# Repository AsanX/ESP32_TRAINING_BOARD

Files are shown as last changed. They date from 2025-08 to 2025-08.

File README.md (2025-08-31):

# ESP32_TRAINING_BOARD

ESP32 Training board is designed to have multiple things to play with so there are lot's of opportunities to learn the ESP32.
I made this board so i can remotely open our front door from 4th floor and figured i could do something else with it too.

- USB-C Charging, programming and serial monitor
- 18650 Battery with commonly used TP4056 charging circuit
- RGB Led
- Button / Encoder
- TMP100 12Bit I2C Temperature sensor
- OLED I2C Display
- Few optocoupler for inputs and outputs

# Alredy found mistakes from HW 1.0
## Enable pin and auto reset
When using automatic reset for programming, there needs to be a uF range capacitor on enable.
This is to make sure the IO0 pin is given some time to pull low to enter the download mode before the en pin gets HIGH.
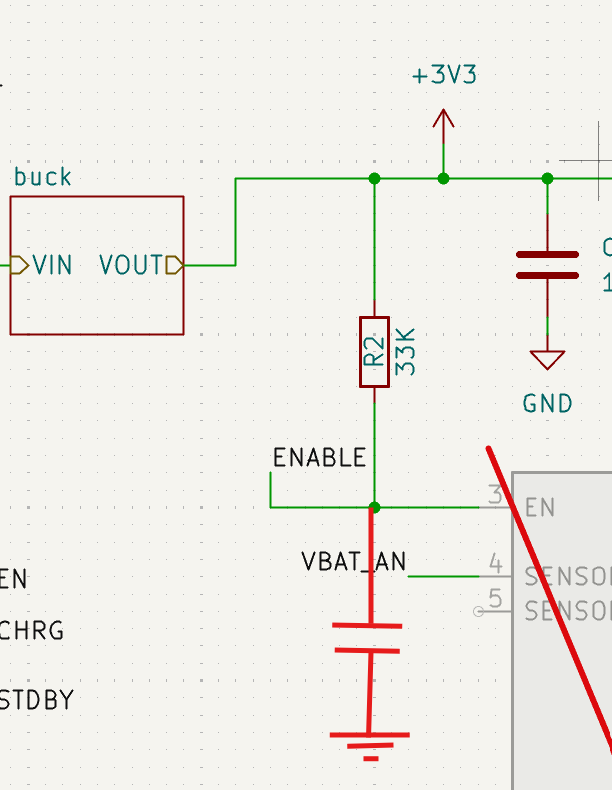
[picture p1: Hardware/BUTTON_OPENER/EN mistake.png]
Alt text for image


## TP4056 temperature pin
Datasheet clearly says that the pin should be pulled low if there are no temperature sensor on the battery
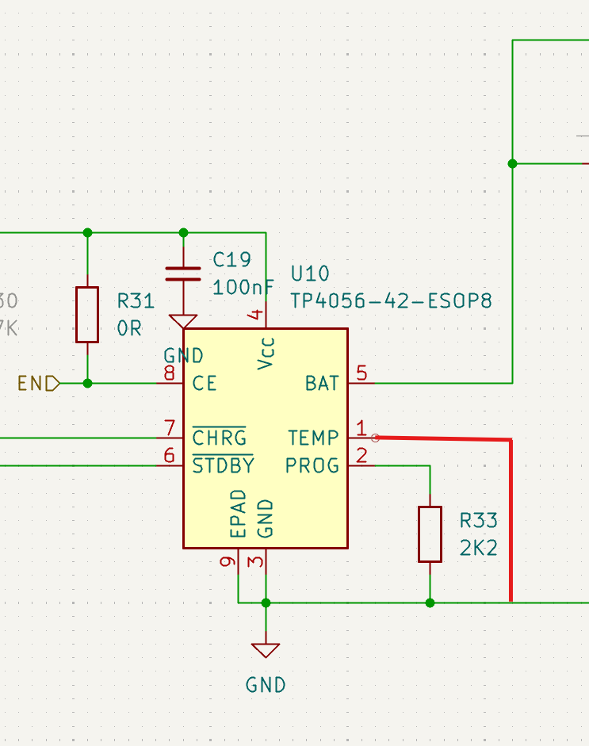
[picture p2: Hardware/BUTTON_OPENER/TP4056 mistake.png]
Alt_text_for_image


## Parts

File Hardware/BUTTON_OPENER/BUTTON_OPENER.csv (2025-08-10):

Comment | Reference | Footprint | JLCPCB Part #
100nF | C4,C5,C6,C7,C8,C10,C11,C12,C13,C14,C15,C17,C18,C19 | Capacitor_SMD:C_0603_1608Metric | C14663
1K | R6,R7,R8,R13,R15,R16,R18,R21,R25,R32 | Resistor_SMD:R_0603_1608Metric | C21190
TCMT1100 | U4,U5,U6,U7 | Package_SO:SOP-4_4.4x2.6mm_P1.27mm | C123196
33K | R2,R3,R9,R17 | Resistor_SMD:R_0603_1608Metric | C4216
47K | R14,R19,R24 | Resistor_SMD:R_0603_1608Metric | C25819
10K | R1,R22,R26 | Resistor_SMD:R_0603_1608Metric | C25804
10uF | C1,C3,C20 | Capacitor_SMD:C_0603_1608Metric | C19702
5K1 | R34,R35 | Resistor_SMD:R_0603_1608Metric | C23186
12K | R23,R27 | Resistor_SMD:R_0603_1608Metric | C22790
3K3 | R11,R12 | Resistor_SMD:R_0603_1608Metric | C22978
6K8 | R4,R5 | Resistor_SMD:R_0603_1608Metric | C23212
BC847 | Q1,Q2 | Package_TO_SOT_SMD:SOT-23 | C475630
4.7uF | C9,C16 | Capacitor_SMD:C_0603_1608Metric | C19666
SUNTEK SK6615CS5 | U11 | Package_TO_SOT_SMD:SOT-23-5 | C2986199
TP4056-42-ESOP8 | U10 | Package_SO:SOIC-8-1EP_3.9x4.9mm_P1.27mm_EP2.41x3.3mm_ThermalVias | C16581
DW01A | U9 | Package_TO_SOT_SMD:SOT-23-6 | C2927799
CP2102N | U8 | Package_DFN_QFN:QFN-24-1EP_4x4mm_P0.5mm_EP2.6x2.6mm | C969151
TMP100 | U3 | Package_TO_SOT_SMD:SOT-23-6 | C31810
120K | R37 | Resistor_SMD:R_0603_1608Metric | C25808
2K2 | R33 | Resistor_SMD:R_0603_1608Metric | C4190
0R | R31 | Resistor_SMD:R_0603_1608Metric | C21189
100R | R28 | Resistor_SMD:R_0603_1608Metric | C22775
8K2 | R20 | Resistor_SMD:R_0603_1608Metric | C25981
1K5 | R10 | Resistor_SMD:R_0603_1608Metric | C22843
BSD840N | Q3 | Package_TO_SOT_SMD:SOT-363_SC-70-6 | C466988
2.2uH | L1 | Inductor_SMD:L_APV_ANR4026 | C167854
USB_C_Receptacle_USB2.0_14P | J7 | Connector_USB:USB_C_Receptacle_G-Switch_GT-USB-7010ASV | C2927039
1uF | C2 | Capacitor_SMD:C_0603_1608Metric | C106248

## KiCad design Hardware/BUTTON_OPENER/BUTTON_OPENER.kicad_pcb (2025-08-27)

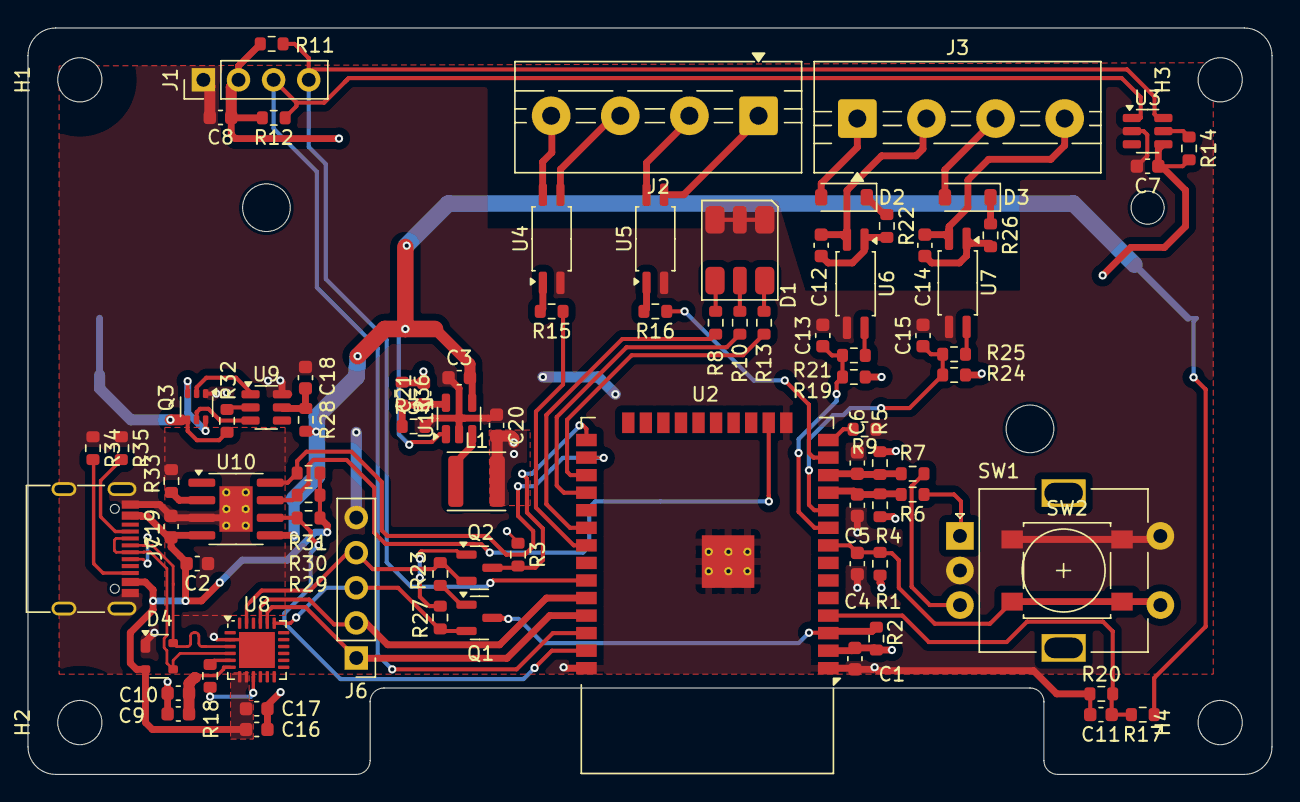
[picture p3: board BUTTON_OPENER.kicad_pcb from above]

Board: 2 copper layers, 90.0 x 54.0 mm, 88 parts (1 on the bottom side), 67 nets.

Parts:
BT1: 18650 holder; BatteryHolder_Keystone_1042_1x18650
C1, C3, C20: 10uF 6.3V X7R; C_0603_1608Metric
C2: 1uF 10V X7R; C_0603_1608Metric
C4, C5, C6, C7, C8, C10, C11, C12, C13, C14, C15, C17, C18, C19: 100nF 10V X7R; C_0603_1608Metric
C9, C16: 4.7uF 10V X7R; C_0603_1608Metric
C21: 22pF; C_0603_1608Metric
D1: Inolux_IN-P55TATRGB; LED_Inolux_IN-P55TATRGB_PLCC6_5.0x5.5mm_P1.8mm
D2, D3: D; D_SOD-123
D4: SP0503BAHT; SOT-143
H1, H2, H3, H4: MountingHole; MountingHole_3.2mm_M3
J1: N/A; PinHeader_1x04_P2.54mm_Vertical
J2, J3: Screw_Terminal_01x04; TerminalBlock_MaiXu_MX126-5.0-04P_1x04_P5.00mm
J6: Conn_01x05; PinHeader_1x05_P2.54mm_Vertical
J7: USB_C_Receptacle_USB2.0_14P; USB_C_Receptacle_G-Switch_GT-USB-7010ASV
L1: 2.2uH; L_APV_ANR4020
Q1, Q2: BC847; SOT-23
Q3: BSD840N; SOT-363_SC-70-6
R1, R22, R26: 10K; R_0603_1608Metric
R2, R3, R9, R17: 33K; R_0603_1608Metric
R4, R5: 6K8; R_0603_1608Metric
R6, R7, R8, R13, R15, R16, R18, R21, R25, R32: 1K; R_0603_1608Metric
R10: 1K5; R_0603_1608Metric
R11, R12: 3K3; R_0603_1608Metric
R14, R19, R24, R29, R30: 47K; R_0603_1608Metric
R20: 8K2; R_0603_1608Metric
R23, R27: 12K; R_0603_1608Metric
R28: 100R; R_0603_1608Metric
R31: 0R; R_0603_1608Metric
R33: 2K2; R_0603_1608Metric
R34, R35: 5K1; R_0603_1608Metric
R36: 540K; R_0603_1608Metric
R37: 120K; R_0603_1608Metric
SW1: N/A; RotaryEncoder_Alps_EC11E-Switch_Vertical_H20mm
SW2: SW_Push; SW_SPST_B3S-1000
U2: ESP32-WROOM; ESP32-WROOM-32D
U3: TMP100; SOT-23-6
U4, U5, U6, U7: TCMT1100; SOP-4_4.4x2.6mm_P1.27mm
U8: CP2102N; QFN-24-1EP_4x4mm_P0.5mm_EP2.6x2.6mm
U9: DW01A; SOT-23-6
U10: TP4056-42-ESOP8; SOIC-8-1EP_3.9x4.9mm_P1.27mm_EP2.41x3.3mm_ThermalVias
U11: SUNTEK SK6615CS5; SOT-23-5

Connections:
+3V3: C1.2, C7.1, C8.1, C20.2, C21.2, J1.2, L1.2, R1.1, R2.1, R3.1, R4.1, R5.1, R11.2, R12.2, R14.2, R19.2, R24.2, R36.1, U2.2 (VDD), U3.4 (V+)
/B: R13.1, U2.27 (IO16)
/CHRG: R30.1, U2.16 (IO13), U10.7 (~CHRG)
/D+: D4.4 (K), J7.A6 (D+), J7.B6 (D+), U8.3 (D+)
/D-: D4.3 (K), J7.A7 (D-), J7.B7 (D-), U8.4 (D-)
/DTR: J6.4, Q2.2 (E), R23.1, U8.23 (~DTR)
/EN: R31.1, U2.26 (IO4), U10.8 (CE)
/ENABLE: Q1.3 (C), R2.2, U2.3 (EN)
/ENC_A: C5.2, R4.2, R6.2, U2.11 (IO26)
/ENC_B: C6.2, R5.2, R7.2, U2.12 (IO27)
/ENC_SW: C4.2, R1.2, SW1.S1, SW2.2, U2.8 (IO32)
/G: R10.1, U2.28 (IO17)
/GPIO0: Q2.3 (C), R3.2, U2.25 (IO0)
/OPTO_1: R15.1, U2.31 (IO19)
/OPTO_2: R16.1, U2.13 (IO14)
/OPTO_IN1: C13.1, R19.1, R21.2, U2.9 (IO33)
/OPTO_IN2: C15.1, R24.1, R25.2, U2.10 (IO25)
/R: R8.1, U2.30 (IO18)
/RTS: J6.3, Q1.2 (E), R27.1, U8.19 (~RTS)
/RXD: J6.2, U2.34 (RXD0/IO3), U8.21 (TXD)
/SCL: J1.3, R12.1, U2.36 (IO22), U3.1 (SCL)
/SDA: J1.4, R11.1, U2.33 (IO21), U3.6 (SDA)
/STDBY: R29.1, U2.37 (IO23), U10.6 (~STDBY)
/TXD: J6.1, U2.35 (TXD0/IO1), U8.20 (RXD)
/VBAT: BT1.1 (+), C3.2, R17.1, R28.2, U10.5 (BAT), U11.1 (EN), U11.4 (VIN)
/VBAT_AN: C11.1, R17.2, R20.1, U2.4 (SENSOR_VP)
/VBUS: C2.2, C16.2, C17.1, C19.1, D4.2 (K), J7.A4 (VBUS), J7.A9 (VBUS), J7.B4 (VBUS), J7.B9 (VBUS), R29.2, R30.2, R31.2, U8.7 (VREGIN), U8.8 (VBUS), U10.4 (V_{CC})
GND: C1.1, C2.1, C3.1, C4.1, C5.1, C6.1, C7.2, C8.2, C9.1, C10.2, C11.2, C13.2, C15.2, C16.1, C17.2, C18.2, C19.2, C20.1, D1.1 (KB), D1.2 (KR), D1.3 (KG), D4.1 (A), J1.1, J6.5, J7.A1 (GND), J7.A12 (GND), J7.B1 (GND), J7.B12 (GND), J7.S1 (SHIELD), Q3.1 (S), R9.2, R20.2, R33.1, R34.1, R35.1, R37.2, SW1.C, SW1.S2, SW2.1, U2.1 (GND), U2.15 (GND), U2.38 (GND), U2.39 (GND), U3.2 (GND), U4.2, U5.2, U6.3, U7.3, U8.2 (GND), U8.25 (GND), U9.6 (GND), U10.3 (GND), U10.9 (EPAD), U11.2 (GND)
unnamed: BT1.2 (-), Q3.4 (S), R32.1
unnamed: C12.1, R22.2, U6.1
unnamed: C14.1, R26.2, U7.1
unnamed: D1.6 (AB), R13.2
unnamed: D1.4 (AG), R8.2
unnamed: D1.5 (AR), R10.2
unnamed: D2.2 (A), J3.1
unnamed: D2.1 (K), R22.1
unnamed: D3.2 (A), J3.3
unnamed: D3.1 (K), R26.1
unnamed: J2.1, U5.3
unnamed: J2.2, U5.4
unnamed: J2.3, U4.3
unnamed: J2.4, U4.4
unnamed: C12.2, J3.2, U6.2
unnamed: C14.2, J3.4, U7.2
unnamed: J7.A5 (CC1), R35.2
unnamed: J7.B5 (CC2), R34.2
unnamed: Q1.1 (B), R23.2
unnamed: Q2.1 (B), R27.2
unnamed: Q3.3 (D), Q3.6 (D)
unnamed: Q3.2 (G), U9.1 (OD)
unnamed: Q3.5 (G), U9.3 (OC)
unnamed: R6.1, SW1.A
unnamed: R7.1, SW1.B
unnamed: R15.2, U4.1
unnamed: R16.2, U5.1
unnamed: R21.1, U6.4
unnamed: R25.1, U7.4
unnamed: R9.1, U2.14 (IO12)
unnamed: R14.1, U3.5 (ADD0)
unnamed: C9.2, C10.1, U8.6 (VDD)
unnamed: R18.1, U8.5 (VIO)
unnamed: R18.2, U8.9 (~RST)
unnamed: R32.2, U9.2 (CS)
unnamed: C18.1, R28.1, U9.5 (VCC)
unnamed: R33.2, U10.2 (PROG)
unnamed: C21.1, R36.2, R37.1, U11.5 (FB)
unnamed: L1.1, U11.3 (SW)

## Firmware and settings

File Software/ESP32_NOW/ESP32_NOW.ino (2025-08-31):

#include <Wire.h>
#include <Adafruit_GFX.h>
#include <Adafruit_SSD1306.h>
#include "ESP32_NOW.h"
#include "WiFi.h"

#define SCREEN_WIDTH 128  // OLED width in pixels
#define SCREEN_HEIGHT 64  // OLED height in pixels

#define ESPNOW_WIFI_CHANNEL 6

uint8_t broadcastAddress[] = {0xFF, 0xFF, 0xFF, 0xFF, 0xFF, 0xFF};

// Declaration for an SSD1306 display connected to I2C (SDA, SCL pins)
#define OLED_RESET    -1  // Reset pin not used
Adafruit_SSD1306 display(SCREEN_WIDTH, SCREEN_HEIGHT, &Wire, OLED_RESET);

// Set up the rgb led names
uint8_t ledR = 18;
uint8_t ledG = 17;
uint8_t ledB = 16;

#define CHARGING_PIN 13     // Pin 13 (Charging signal from TP4056)
#define STANDBY_PIN 23      // Pin 23 (STANDBY signal from TP4056)
#define EN_PIN 4            // Pin 4  (EN signal for TP4056)
#define SW_PIN 32           // Pin 32 (SW / Encoder SW)

struct Input {
  const uint8_t PIN;
  uint32_t events;
  bool active;
};

Input charging = {CHARGING_PIN, 0, false};
Input standby = {STANDBY_PIN, 0, false};
Input sw = {SW_PIN, 0, false};


/* Interrupt service*/
void ARDUINO_ISR_ATTR isr(void *arg) 
{
  Input *s = static_cast<Input *>(arg);
  s->events += 1;
  s->active = true;
}

class ESP_NOW_Broadcast_Peer : public ESP_NOW_Peer {
public:
  // Constructor of the class using the broadcast address
  ESP_NOW_Broadcast_Peer(uint8_t channel, wifi_interface_t iface, const uint8_t *lmk) : ESP_NOW_Peer(ESP_NOW.BROADCAST_ADDR, channel, iface, lmk) {}

  // Destructor of the class
  ~ESP_NOW_Broadcast_Peer() {
    remove();
  }

  // Function to properly initialize the ESP-NOW and register the broadcast peer
  bool begin() {
    if (!ESP_NOW.begin() || !add()) {
      log_e("Failed to initialize ESP-NOW or register the broadcast peer");
      return false;
    }
    return true;
  }

  // Function to send a message to all devices within the network
  bool send_message(const uint8_t *data, size_t len) {
    if (!send(data, len)) {
      log_e("Failed to broadcast message");
      return false;
    }
    return true;
  }
};

/* Global Variables */
uint32_t msg_count = 0;

// Create a broadcast peer object
ESP_NOW_Broadcast_Peer broadcast_peer(ESPNOW_WIFI_CHANNEL, WIFI_IF_STA, nullptr);

// the setup routine runs once when you press reset:
void setup() {
  Serial.begin(115200);
  delay(10);

   // Initialize OLED
  if(!display.begin(SSD1306_SWITCHCAPVCC, 0x3C)) {  // Address 0x3C for 128x64
    Serial.println(F("SSD1306 allocation failed"));
    while(true);  // Don't proceed, loop forever
  }

  display.clearDisplay();
  display.setTextSize(1);             // Normal 1:1 pixel scale
  display.setTextColor(SSD1306_WHITE); // Draw white text
  display.setCursor(0, 0);            // Start at top-left corner
  display.display();                  // Show on screen

  ledcAttach(ledR, 3000, 8);  // 12 kHz PWM, 8-bit resolution
  ledcAttach(ledG, 3000, 8);
  ledcAttach(ledB, 3000, 8);

  // Set pinmodes
  pinMode(CHARGING_PIN, INPUT_PULLUP);   
  pinMode(STANDBY_PIN, INPUT_PULLUP);  
  pinMode(SW_PIN, INPUT_PULLUP);  
  pinMode(EN_PIN, OUTPUT_OPEN_DRAIN); 

  attachInterruptArg(SW_PIN, isr, &sw, FALLING);

  analogReadResolution(12);

  // Initialize the Wi-Fi module
  WiFi.mode(WIFI_STA);
  WiFi.setChannel(ESPNOW_WIFI_CHANNEL);
  while (!WiFi.STA.started()) {
    delay(100);
  }

  Serial.println("ESP-NOW Example - Broadcast Master");
  Serial.println("Wi-Fi parameters:");
  Serial.println("  Mode: STA");
  Serial.println("  MAC Address: " + WiFi.macAddress());
  Serial.printf("  Channel: %d\n", ESPNOW_WIFI_CHANNEL);

  // Register the broadcast peer
  if (!broadcast_peer.begin()) {
    Serial.println("Failed to initialize broadcast peer");
    Serial.println("Reebooting in 5 seconds...");
    delay(5000);
    ESP.restart();
  }

  Serial.printf("ESP-NOW version: %d, max data length: %d\n", ESP_NOW.getVersion(), ESP_NOW.getMaxDataLen());

  Serial.println("Setup complete. Broadcasting messages every 5 seconds.");

}


// void loop runs over and over again
void loop() 
{
  if (sw.active == true)
  {
    ledcWrite(ledB, 255);
    sw.active = false;

      // Broadcast a message to all devices within the network
    char data[32];
    snprintf(data, sizeof(data), "Hello, World! #%lu", msg_count++);

    Serial.printf("Broadcasting message: %s\n", data);

    if (!broadcast_peer.send_message((uint8_t *)data, sizeof(data))) {
      Serial.println("Failed to broadcast message");
    }

  }

  static uint32_t lastMillis = 0;
  if (millis() - lastMillis > 3000) {
    lastMillis = millis();
    ledcWrite(ledB,0);
    ledcWrite(ledR,0);
    ledcWrite(ledG,0);
  }
}

/* Use this to convert ADC millivolts to Battery millivolts */
uint16_t adcmV_to_batmV(uint16_t mV)
{
  // Reverse voltage divider to get actual battery voltage (also in millivolts)
  // Vbat = Vadc * (R1 + R2) / R2
  uint16_t vBat = (uint32_t)mV * (33000 + 8200) / 8200;

  return vBat;
}

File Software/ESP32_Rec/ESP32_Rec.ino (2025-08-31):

/*
    ESP-NOW Broadcast Slave
    Lucas Saavedra Vaz - 2024

    This sketch demonstrates how to receive broadcast messages from a master device using the ESP-NOW protocol.

    The master device will broadcast a message every 5 seconds to all devices within the network.

    The slave devices will receive the broadcasted messages. If they are not from a known master, they will be registered as a new master
    using a callback function.
*/

#include <Wire.h>
#include <Adafruit_GFX.h>
#include <Adafruit_SSD1306.h>

#include "ESP32_NOW.h"
#include "WiFi.h"

#include <esp_mac.h>  // For the MAC2STR and MACSTR macros

#include <vector>

/* Definitions */

#define ESPNOW_WIFI_CHANNEL 6

#define OPTO1 19
#define OPTO2 14
// Set up the rgb led names
const uint8_t ledR = 18;
const uint8_t ledG = 17;
const uint8_t ledB = 16;

/* Classes */

// Creating a new class that inherits from the ESP_NOW_Peer class is required.

class ESP_NOW_Peer_Class : public ESP_NOW_Peer {
public:
  // Constructor of the class
  ESP_NOW_Peer_Class(const uint8_t *mac_addr, uint8_t channel, wifi_interface_t iface, const uint8_t *lmk) : ESP_NOW_Peer(mac_addr, channel, iface, lmk) {}

  // Destructor of the class
  ~ESP_NOW_Peer_Class() {}

  // Function to register the master peer
  bool add_peer() {
    if (!add()) {
      log_e("Failed to register the broadcast peer");
      return false;
    }
    return true;
  }

  // Function to print the received messages from the master
  void onReceive(const uint8_t *data, size_t len, bool broadcast) {
    Serial.printf("Received a message from master " MACSTR " (%s)\n", MAC2STR(addr()), broadcast ? "broadcast" : "unicast");
    Serial.printf("  Message: %s\n", (char *)data);
    ledcWrite(ledG, 200);
    digitalWrite(OPTO1, HIGH);
    digitalWrite(OPTO2, LOW);

  }
};
 
/* Global Variables */

// List of all the masters. It will be populated when a new master is registered
// Note: Using pointers instead of objects to prevent dangling pointers when the vector reallocates
std::vector<ESP_NOW_Peer_Class *> masters;

/* Callbacks */

// Callback called when an unknown peer sends a message
void register_new_master(const esp_now_recv_info_t *info, const uint8_t *data, int len, void *arg) {
  if (memcmp(info->des_addr, ESP_NOW.BROADCAST_ADDR, 6) == 0) {
    Serial.printf("Unknown peer " MACSTR " sent a broadcast message\n", MAC2STR(info->src_addr));
    Serial.println("Registering the peer as a master");

    ESP_NOW_Peer_Class *new_master = new ESP_NOW_Peer_Class(info->src_addr, ESPNOW_WIFI_CHANNEL, WIFI_IF_STA, nullptr);
    if (!new_master->add_peer()) {
      Serial.println("Failed to register the new master");
      delete new_master;
      return;
    }
    masters.push_back(new_master);
    Serial.printf("Successfully registered master " MACSTR " (total masters: %zu)\n", MAC2STR(new_master->addr()), masters.size());
  } else {
    // The slave will only receive broadcast messages
    log_v("Received a unicast message from " MACSTR, MAC2STR(info->src_addr));
    log_v("Igorning the message");
  }
}

/* Main */

void setup() {
  Serial.begin(115200);

  pinMode(OPTO1, OUTPUT);
  pinMode(OPTO2, OUTPUT);

  digitalWrite(OPTO1, LOW);
  digitalWrite(OPTO2, HIGH);

  ledcAttach(ledG, 3000, 8);

  // Initialize the Wi-Fi module
  WiFi.mode(WIFI_STA);
  WiFi.setChannel(ESPNOW_WIFI_CHANNEL);
  while (!WiFi.STA.started()) {
    delay(100);
  }

  Serial.println("ESP-NOW Example - Broadcast Slave");
  Serial.println("Wi-Fi parameters:");
  Serial.println("  Mode: STA");
  Serial.println("  MAC Address: " + WiFi.macAddress());
  Serial.printf("  Channel: %d\n", ESPNOW_WIFI_CHANNEL);

  // Initialize the ESP-NOW protocol
  if (!ESP_NOW.begin()) {
    Serial.println("Failed to initialize ESP-NOW");
    Serial.println("Reeboting in 5 seconds...");
    delay(5000);
    ESP.restart();
  }

  Serial.printf("ESP-NOW version: %d, max data length: %d\n", ESP_NOW.getVersion(), ESP_NOW.getMaxDataLen());

  // Register the new peer callback
  ESP_NOW.onNewPeer(register_new_master, nullptr);

  Serial.println("Setup complete. Waiting for a master to broadcast a message...");
}

void loop() {
  // Print debug information every 10 seconds
  static unsigned long last_debug = 0;
  if (millis() - last_debug > 10000) {
    ledcWrite(ledG, 0);
    digitalWrite(OPTO1, LOW);
    digitalWrite(OPTO2, HIGH);
    last_debug = millis();
    Serial.printf("Registered masters: %zu\n", masters.size());
    for (size_t i = 0; i < masters.size(); i++) {
      if (masters[i]) {
        Serial.printf("  Master %zu: " MACSTR "\n", i, MAC2STR(masters[i]->addr()));
      }
    }
  }

  delay(100);
}

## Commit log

2025-08-08 Updated HW
    [BUTTON_OPENER.kicad_pcb, BUTTON_OPENER.kicad_sch]
2025-08-09 Update
    Connectors to screw terminals
    Regulator to low dropout buck
    USB C CC Resistors
    IO2 pulldown resistor added
    [BUTTON_OPENER.kicad_pcb, BUTTON_OPENER.kicad_sch, buck.kicad_sch]
2025-08-10 PCB ordered with this commit
    [BUTTON_OPENER.csv, BUTTON_OPENER.kicad_pcb, BUTTON_OPENER.kicad_sch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]
2025-08-27 Test software
    - Oled
    - LEDs
    - Charger status
    - Battery voltage to oled
    [BUTTON_OPENER.csv, BUTTON_OPENER.kicad_pcb, BUTTON_OPENER.kicad_sch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]
2025-08-27 Temp sensor
    Trying to make the TMP100 work with LM75 derived driveer but its printing -0.06c
2025-08-31 Working prototype of master / slave
    This code is pretty much from the ESP api.
